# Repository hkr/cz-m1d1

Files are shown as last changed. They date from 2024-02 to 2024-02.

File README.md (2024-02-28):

# cz-m1d1
Alternative CZ-6BM1

Board cuts and footprints are from Midiori project.
Some footprints and symbols are downloaded from Digikey and/or Mouser.

## Testing status

### tested:
- MIDI out
- MIDI through/out2 switch
- MIDI through
- MIDI in only as part of MIDI through test

### untested:
- tape sync
- address and interrupt configurarion

## Changelog

- mk1 initial prototype
- mk2 change board design to match the look of the original CZ-6BM1
- minor silkscreen fix after that, but I have not built a card with it

## Pics
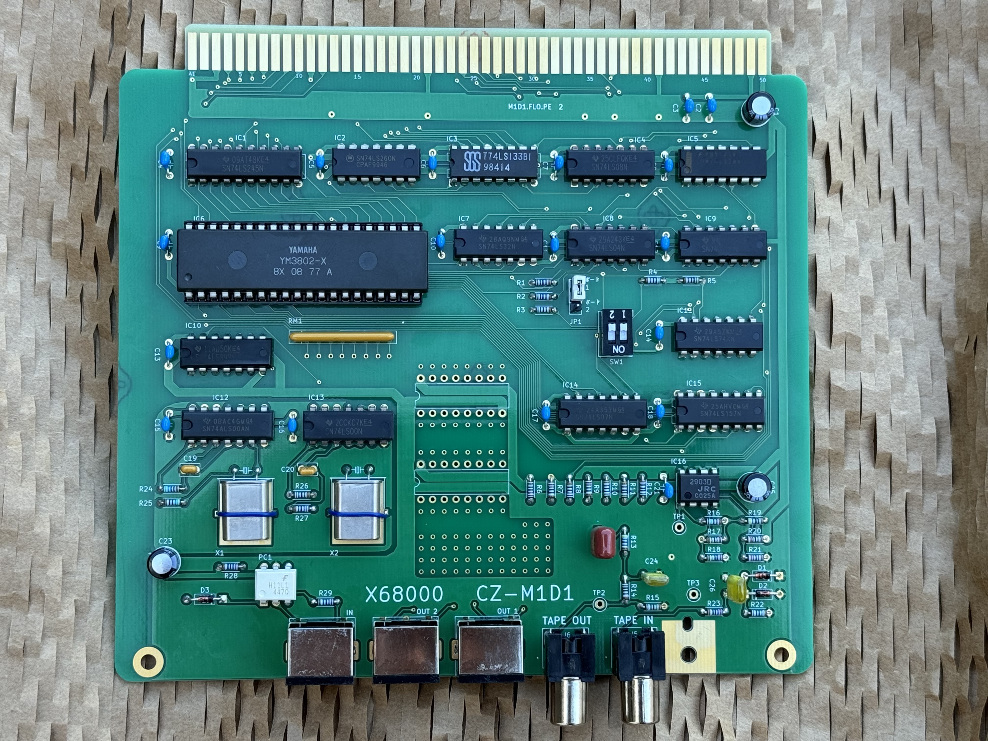
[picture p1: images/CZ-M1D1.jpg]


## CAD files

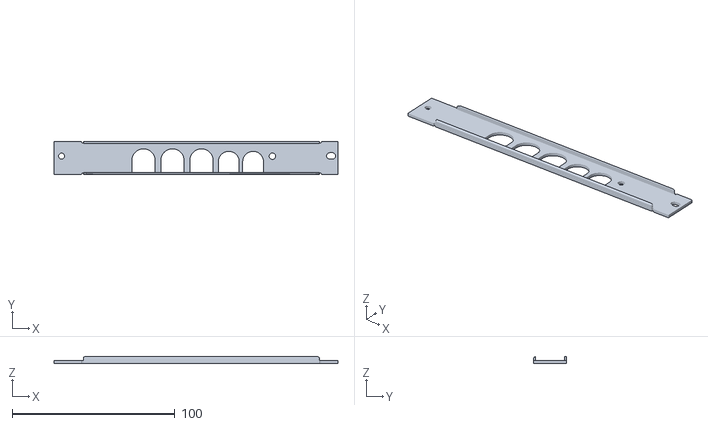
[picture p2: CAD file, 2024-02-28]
CZ-M1D1 cover.stl
174.6 x 20.3 x 4.00

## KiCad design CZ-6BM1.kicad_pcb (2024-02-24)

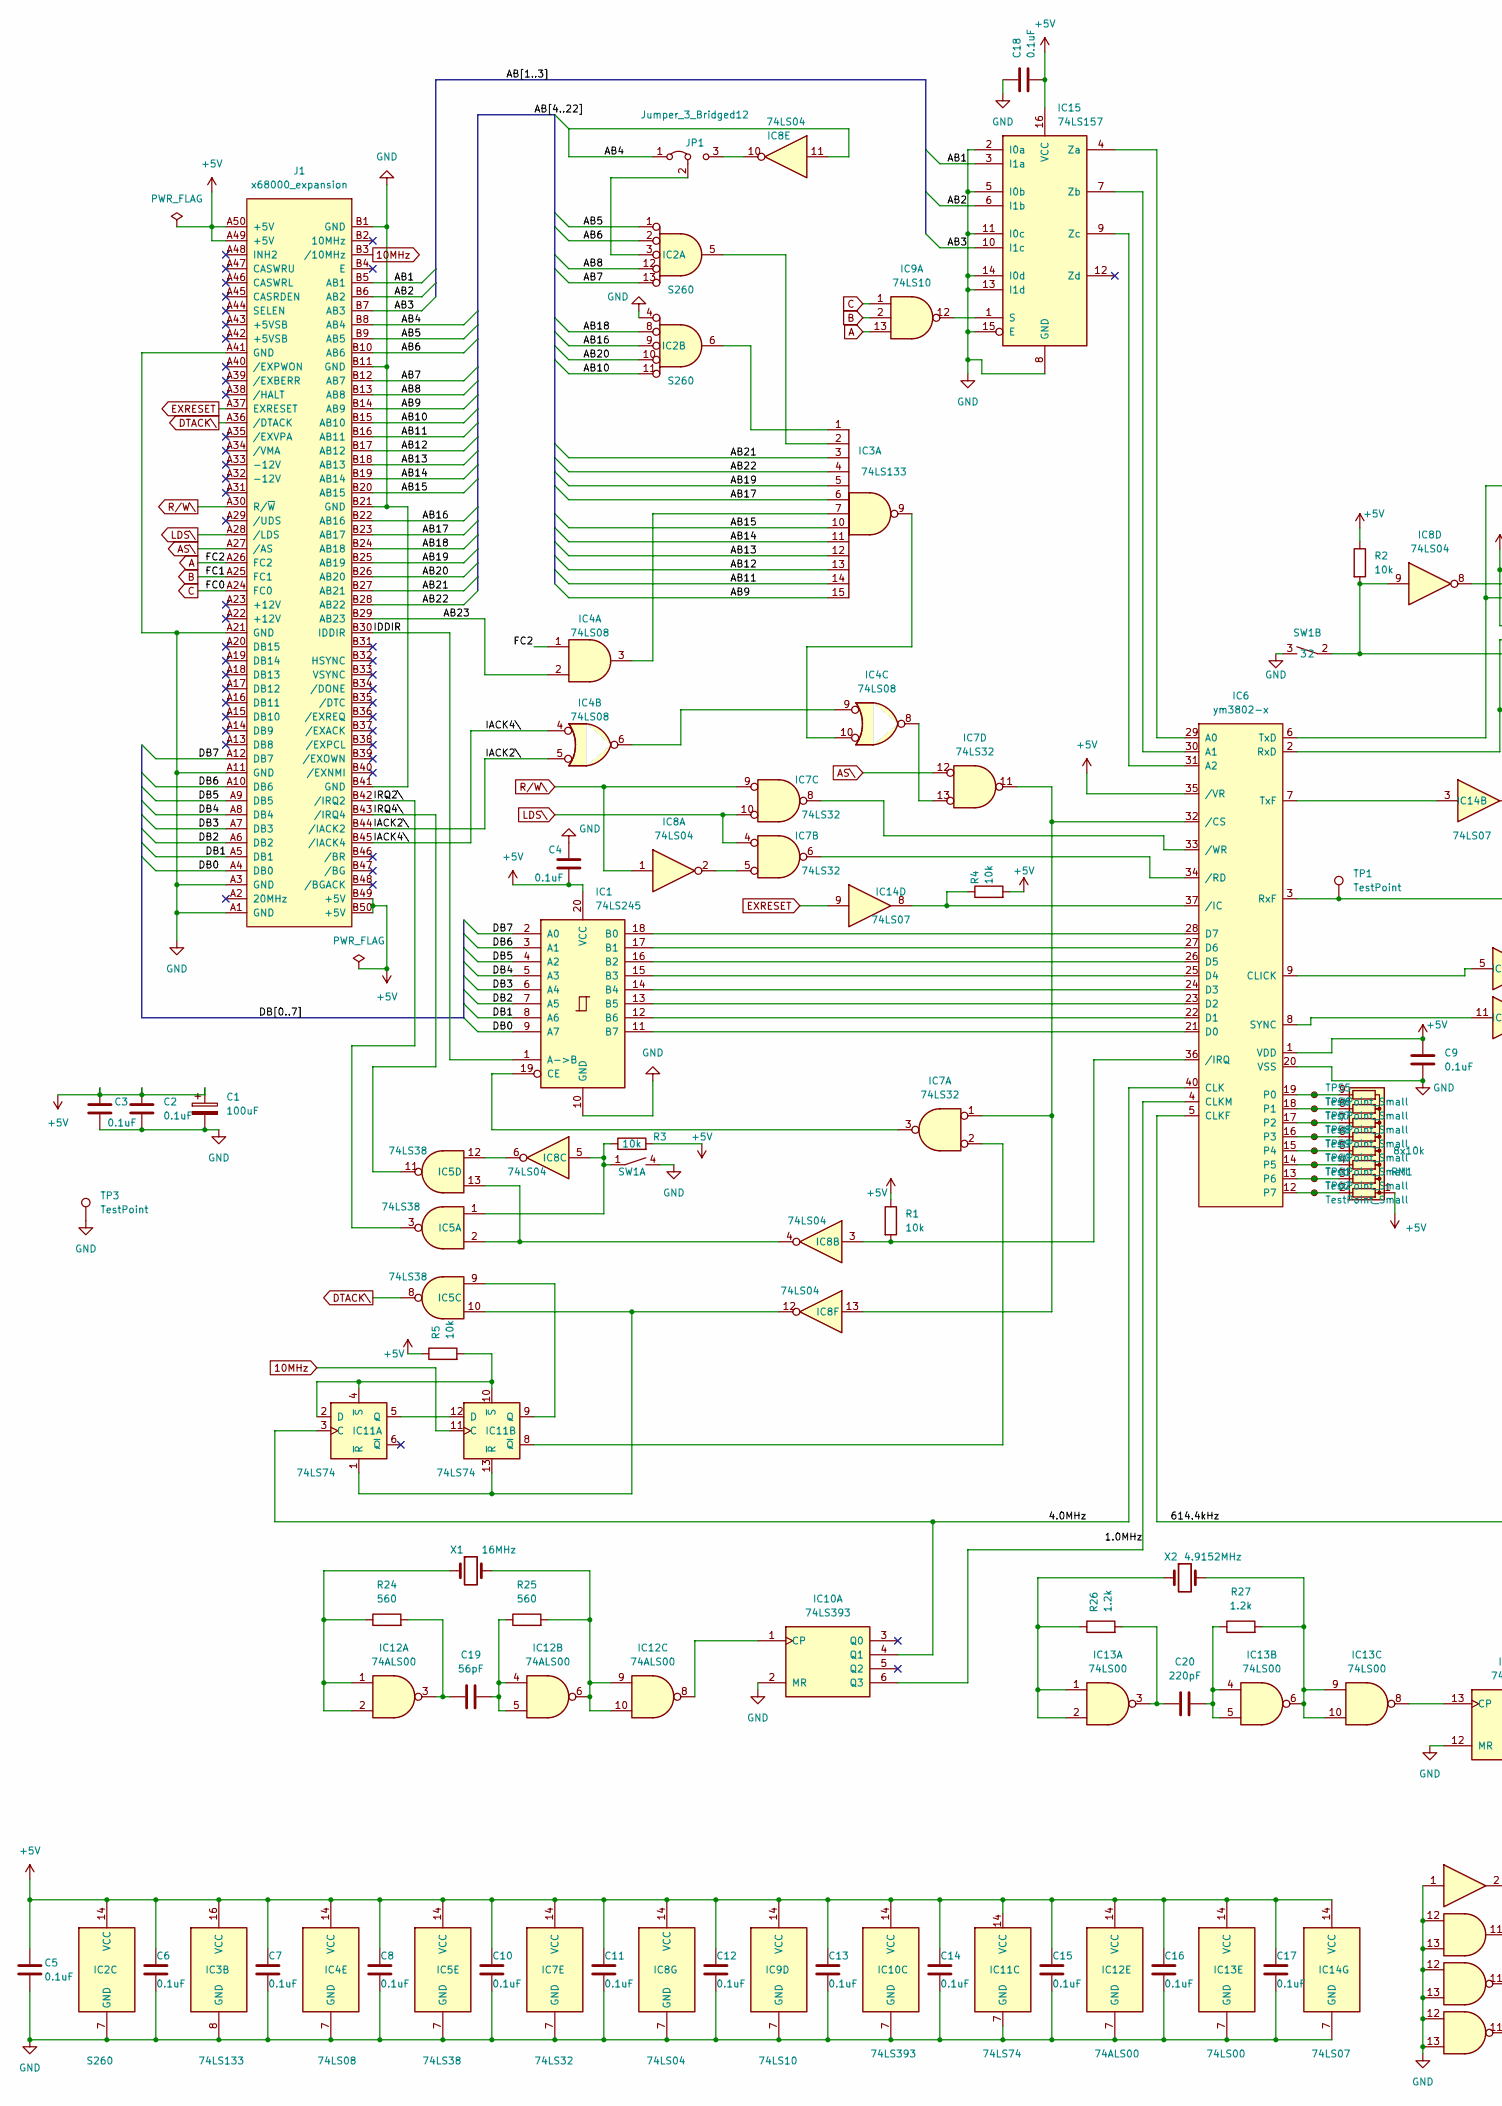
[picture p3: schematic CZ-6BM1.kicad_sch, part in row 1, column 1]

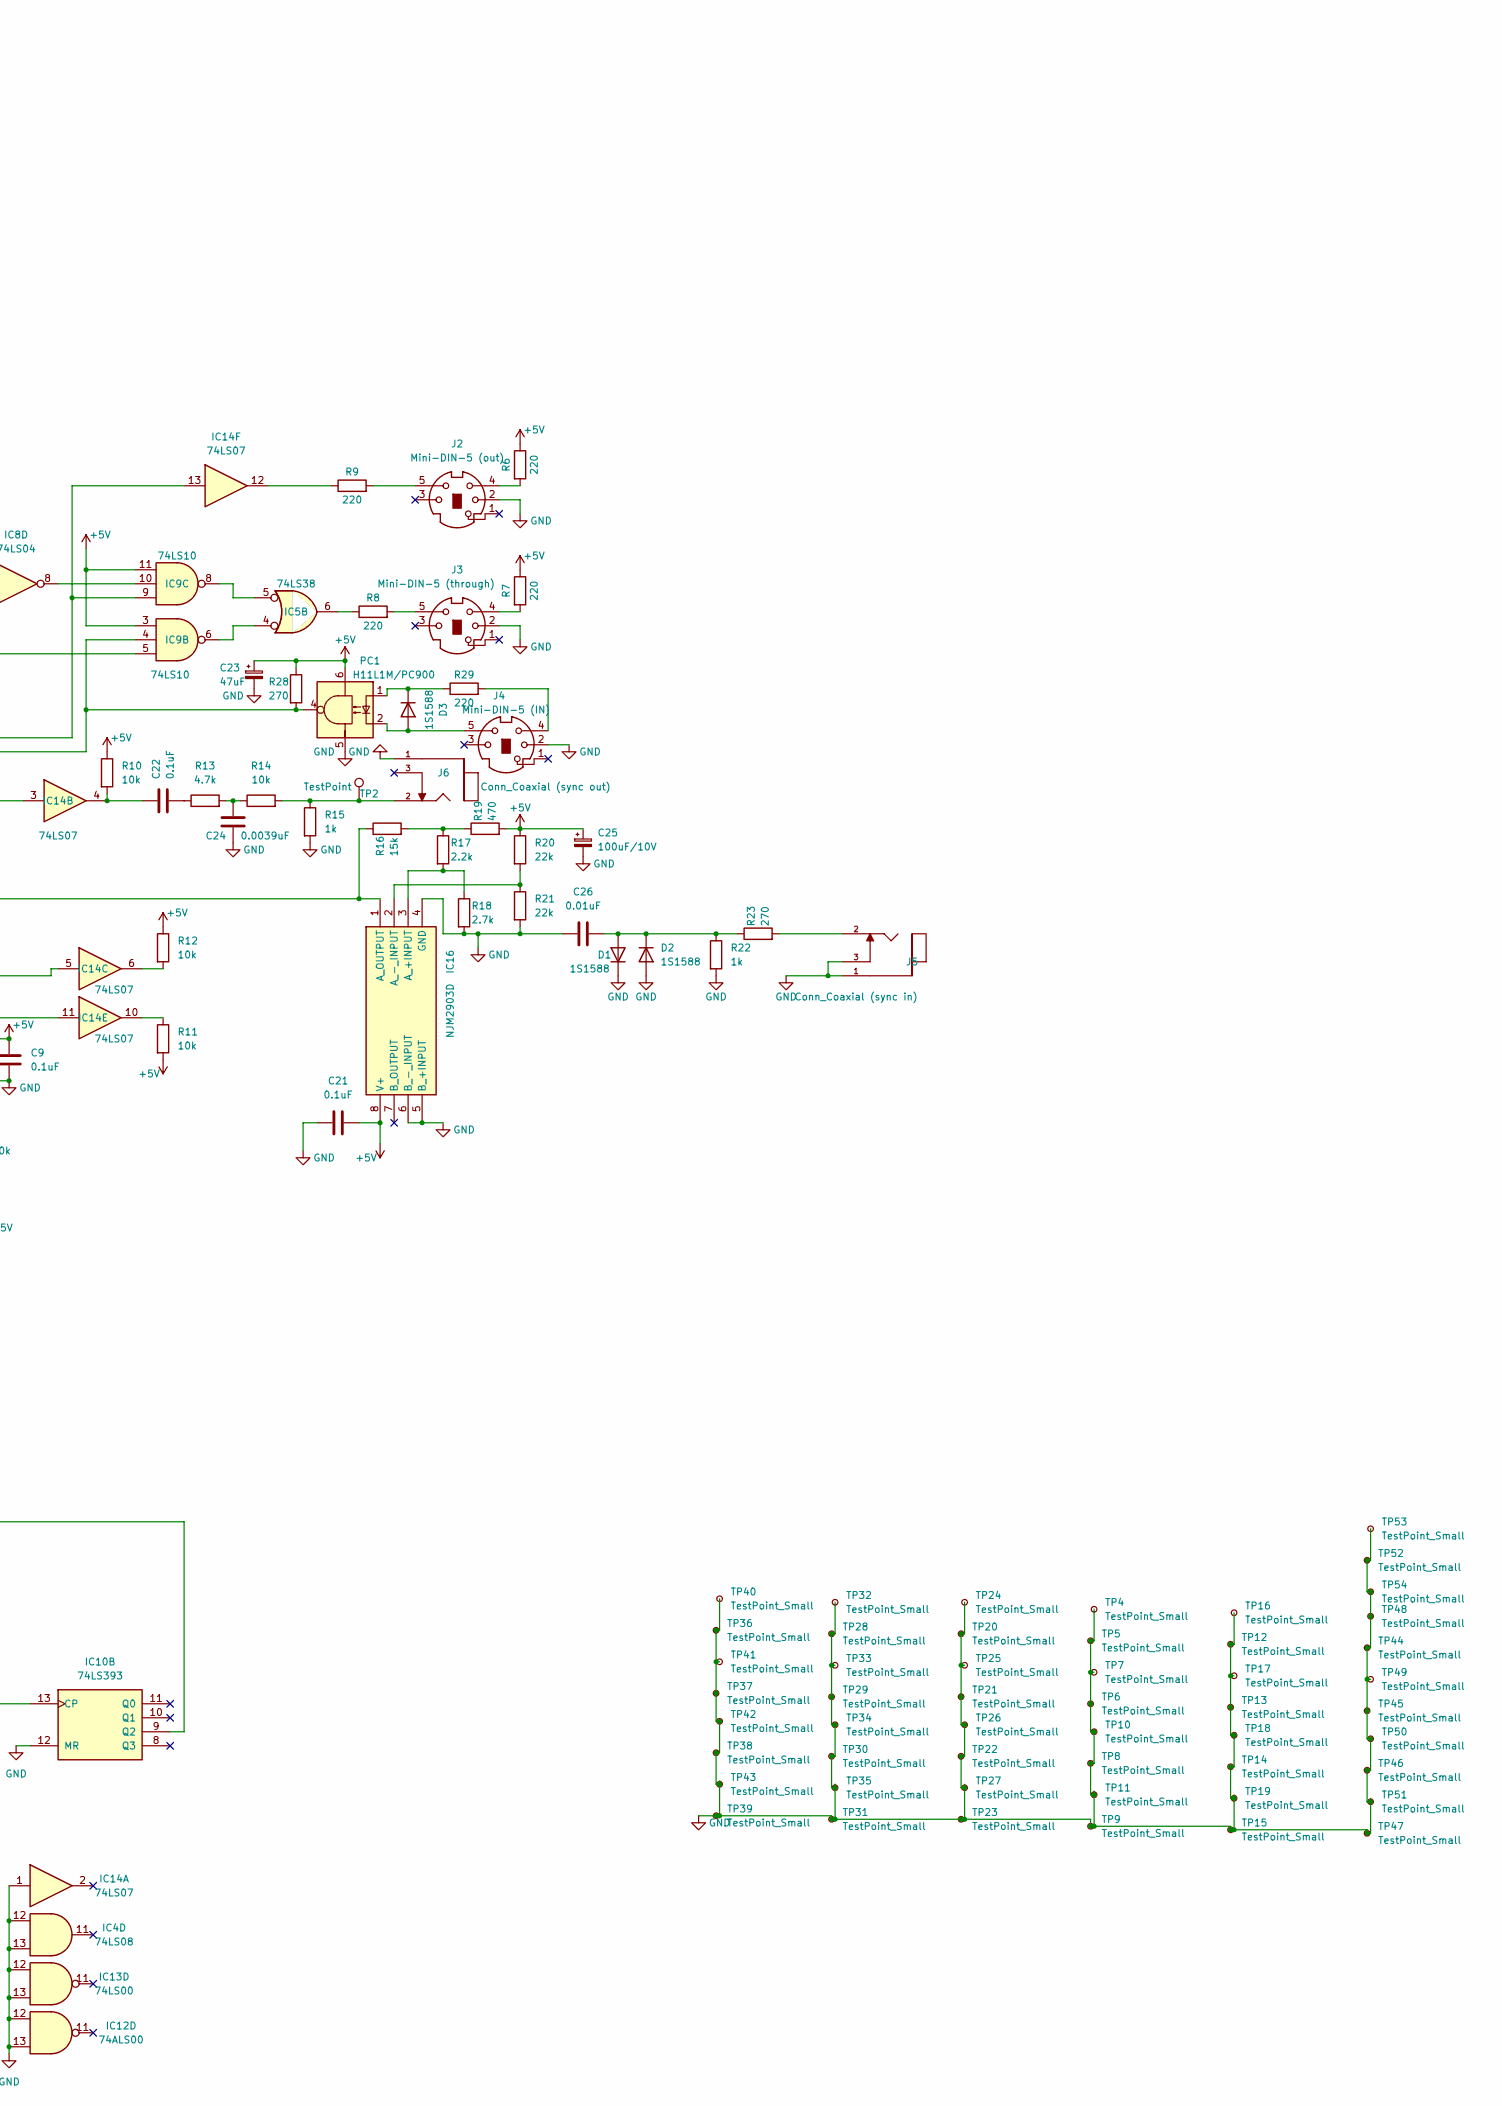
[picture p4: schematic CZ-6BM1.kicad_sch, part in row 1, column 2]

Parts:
C1: 100uF; CP_Radial_D6.3mm_P2.50mm
C2, C3, C4, C5, C6, C7, C8, C9, C10, C11, C12, C13, C14, C15, C16, C17, C18, C21: 0.1uF; C_Rect_L7.0mm_W2.5mm_P5.00mm
C19: 56pF; C_Rect_L4.0mm_W2.5mm_P2.50mm
C20: 220pF; C_Rect_L4.0mm_W2.5mm_P2.50mm
C22: 0.1uF; ECQE2104JB
C23: 47uF; CP_Radial_D6.3mm_P2.50mm
C24: 0.0039uF; CAP_QYX_3P5X6X8P5_NCH
C25: 100uF/10V; CP_Radial_D6.3mm_P2.50mm
C26: 0.01uF; CAP_QYX_3P5X6X8P5_NCH
D1, D2, D3: 1S1588; D_DO-35_SOD27_P7.62mm_Horizontal
IC1: 74LS245; DIP-20_W7.62mm
IC2: S260; DIP-14_W7.62mm
IC3: 74LS133; DIP-16_W7.62mm
IC4: 74LS08; DIP-14_W7.62mm
IC5: 74LS38; DIP-14_W7.62mm
IC6: ym3802-x; DIP-40_W15.24mm
IC7: 74LS32; DIP-14_W7.62mm
IC8: 74LS04; DIP-14_W7.62mm
IC9: 74LS10; DIP-14_W7.62mm
IC10: 74LS393; DIP-14_W7.62mm
IC11: 74LS74; DIP-14_W7.62mm
IC12: 74ALS00; DIP-14_W7.62mm
IC13: 74LS00; DIP-14_W7.62mm
IC14: 74LS07; DIP-14_W7.62mm
IC15: 74LS157; DIP-16_W7.62mm
IC16: NJM2903D; DIP762W56P254L880H425Q8N; Mouser Part Number 513-NJM2903D
J1: x68000_expansion
J2: Mini-DIN-5 (out); MD-50SM
J3: Mini-DIN-5 (through); MD-50SM
J4: Mini-DIN-5 (IN); MD-50SM
J5: Conn_Coaxial (sync in); SWITCHCRAFT_PJRAN1X1U01X; PART_REV B
J6: Conn_Coaxial (sync out); SWITCHCRAFT_PJRAN1X1U01X; PART_REV B
JP1: Jumper_3_Bridged12; PinHeader_1x03_P2.54mm_Vertical
PC1: H11L1M/PC900; DIP-6_W7.62mm
R1, R2, R3, R4, R5, R10, R11, R12, R14: 10k; R_Axial_DIN0204_L3.6mm_D1.6mm_P5.08mm_Horizontal
R6, R7, R8, R9, R29: 220; R_Axial_DIN0204_L3.6mm_D1.6mm_P5.08mm_Horizontal
R13: 4.7k; R_Axial_DIN0204_L3.6mm_D1.6mm_P5.08mm_Horizontal
R15, R22: 1k; R_Axial_DIN0204_L3.6mm_D1.6mm_P5.08mm_Horizontal
R16: 15k; R_Axial_DIN0204_L3.6mm_D1.6mm_P5.08mm_Horizontal
R17: 2.2k; R_Axial_DIN0204_L3.6mm_D1.6mm_P5.08mm_Horizontal
R18: 2.7k; R_Axial_DIN0204_L3.6mm_D1.6mm_P5.08mm_Horizontal
R19: 470; R_Axial_DIN0204_L3.6mm_D1.6mm_P5.08mm_Horizontal
R20, R21: 22k; R_Axial_DIN0204_L3.6mm_D1.6mm_P5.08mm_Horizontal
R23, R28: 270; R_Axial_DIN0204_L3.6mm_D1.6mm_P5.08mm_Horizontal
R24, R25: 560; R_Axial_DIN0204_L3.6mm_D1.6mm_P5.08mm_Horizontal
R26, R27: 1.2k; R_Axial_DIN0204_L3.6mm_D1.6mm_P5.08mm_Horizontal
RM1: 8x10k; R_Array_SIP9
SW1: SW_DIP_SPSTx02_Slide_9.78x7.26mm_W7.62mm_P2.54mm
TP1, TP2, TP3: TestPoint; TestPoint_Loop_D2.50mm_Drill1.0mm
TP4, TP5, TP6, TP7, TP8, TP9, TP10, TP11, TP12, TP13, TP14, TP15, TP16, TP17, TP18, TP19, TP20, TP21, TP22, TP23, TP24, TP25, TP26, TP27, TP28, TP29, TP30, TP31, TP32, TP33, TP34, TP35, TP36, TP37, TP38, TP39, TP40, TP41, TP42, TP43, TP44, TP45, TP46, TP47, TP48, TP49, TP50, TP51, TP52, TP53, TP54, TP55, TP56, TP57, TP58, TP59, TP60, TP61, TP62: TestPoint_Small; TestPoint_THTPad_D1.0mm_Drill0.5mm
X1: 16MHz; Crystal_HC49-U_Horizontal_1EP_style2
X2: 4.9152MHz; Crystal_HC49-U_Horizontal_1EP_style2

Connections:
10MHz: IC11.11 (C), J1.B3 (/10MHz)
+5V: C1.1, C2.1, C3.1, C4.2, C5.1, C6.1, C7.1, C8.1, C9.1, C10.1, C11.1, C12.1, C13.1, C14.1, C15.1, C16.1, C17.1, C18.2, C21.2, C23.1, C25.1, IC1.20 (VCC), IC2.14 (VCC), IC3.16 (VCC), IC4.14 (VCC), IC5.14 (VCC), IC6.1 (VDD), IC6.35 (/VR), IC7.14 (VCC), IC8.14 (VCC), IC9.3, IC9.11, IC9.14 (VCC), IC10.14 (VCC), IC11.14 (VCC), IC12.14 (VCC), IC13.14 (VCC), IC14.14 (VCC), IC15.16 (VCC), IC16.8 (V+), J1.A49 (+5V), J1.A50 (+5V), J1.B49 (+5V), J1.B50 (+5V), PC1.6, R1.1, R2.1, R3.2, R4.2, R5.1, R6.1, R7.1, R10.1, R11.2, R12.1, R19.2, R20.1, R28.1, RM1.1 (common)
/1.0MHz: IC6.4 (CLKM), IC10.6 (Q3)
/4.0MHz: IC6.40 (CLK), IC10.4 (Q1), IC11.3 (C)
/614.4kHz: IC6.5 (CLKF), IC10.9 (Q2)
/AB1: IC15.3 (I1a), J1.B5 (AB1)
/AB2: IC15.6 (I1b), J1.B6 (AB2)
/AB3: IC15.10 (I1c), J1.B7 (AB3)
/AB4: IC8.11, J1.B8 (AB4), JP1.1 (A)
/AB5: IC2.1, J1.B9 (AB5)
/AB6: IC2.2, J1.B10 (AB6)
/AB7: IC2.13, J1.B12 (AB7)
/AB8: IC2.12, J1.B13 (AB8)
/AB9: IC3.15, J1.B14 (AB9)
/AB10: IC2.11, J1.B15 (AB10)
/AB11: IC3.14, J1.B16 (AB11)
/AB12: IC3.13, J1.B17 (AB12)
/AB13: IC3.12, J1.B18 (AB13)
/AB14: IC3.11, J1.B19 (AB14)
/AB15: IC3.10, J1.B20 (AB15)
/AB16: IC2.9, J1.B22 (AB16)
/AB17: IC3.6, J1.B23 (AB17)
/AB18: IC2.8, J1.B24 (AB18)
/AB19: IC3.5, J1.B25 (AB19)
/AB20: IC2.10, J1.B26 (AB20)
/AB21: IC3.3, J1.B27 (AB21)
/AB22: IC3.4, J1.B28 (AB22)
/AB23: IC4.2, J1.B29 (AB23)
/DB0: IC1.9 (A7), J1.A4 (DB0)
/DB1: IC1.8 (A6), J1.A5 (DB1)
/DB2: IC1.7 (A5), J1.A6 (DB2)
/DB3: IC1.6 (A4), J1.A7 (DB3)
/DB4: IC1.5 (A3), J1.A8 (DB4)
/DB5: IC1.4 (A2), J1.A9 (DB5)
/DB6: IC1.3 (A1), J1.A10 (DB6)
/DB7: IC1.2 (A0), J1.A12 (DB7)
/IACK2\: IC4.5, J1.B44 (/IACK2)
/IACK4\: IC4.4, J1.B45 (/IACK4)
/IDDIR: IC1.1 (A->B), J1.B30 (IDDIR)
/IRQ2\: IC5.3, J1.B42 (/IRQ2)
/IRQ4\: IC5.11, J1.B43 (/IRQ4)
A: IC4.1, IC9.13, J1.A26 (FC2)
AS\: IC7.12, J1.A27 (/AS)
B: IC9.2, J1.A25 (FC1)
C: IC9.1, J1.A24 (FC0)
DTACK\: IC5.8, J1.A36 (/DTACK)
EXRESET: IC14.9, J1.A37 (EXRESET)
GND: C1.2, C2.2, C3.2, C4.1, C5.2, C6.2, C7.2, C8.2, C9.2, C10.2, C11.2, C12.2, C13.2, C14.2, C15.2, C16.2, C17.2, C18.1, C21.1, C23.2, C24.2, C25.2, C26.1, D1.1 (K), D2.2 (A), IC1.10 (GND), IC2.4, IC2.7 (GND), IC3.8 (GND), IC4.7 (GND), IC4.12, IC4.13, IC5.7 (GND), IC6.20 (VSS), IC7.7 (GND), IC8.7 (GND), IC9.7 (GND), IC10.2 (MR), IC10.7 (GND), IC10.12 (MR), IC11.7 (GND), IC12.7 (GND), IC12.12, IC12.13, IC13.7 (GND), IC13.12, IC13.13, IC14.1, IC14.7 (GND), IC15.2 (I0a), IC15.5 (I0b), IC15.8 (GND), IC15.11 (I0c), IC15.13 (I1d), IC15.14 (I0d), IC15.15 (E), IC16.4 (GND), IC16.5 (B_+INPUT), IC16.6 (B_-_INPUT), J1.A1 (GND), J1.A3 (GND), J1.A11 (GND), J1.A21 (GND), J1.A41 (GND), J1.B1 (GND), J1.B11 (GND), J1.B21 (GND), J1.B41 (GND), J2.2, J3.2, J4.2, J5.1, J5.3, J6.1, PC1.5, R15.2, R18.2, R21.2, R22.2, SW1.3, SW1.4, TP3.1, TP4.1, TP5.1, TP6.1, TP7.1, TP8.1, TP9.1, TP10.1, TP11.1, TP12.1, TP13.1, TP14.1, TP15.1, TP16.1, TP17.1, TP18.1, TP19.1, TP20.1, TP21.1, TP22.1, TP23.1, TP24.1, TP25.1, TP26.1, TP27.1, TP28.1, TP29.1, TP30.1, TP31.1, TP32.1, TP33.1, TP34.1, TP35.1, TP36.1, TP37.1, TP38.1, TP39.1, TP40.1, TP41.1, TP42.1, TP43.1, TP44.1, TP45.1, TP46.1, TP47.1, TP48.1, TP49.1, TP50.1, TP51.1, TP52.1, TP53.1, TP54.1
LDS\: IC7.4, IC7.10, J1.A28 (/LDS)
unnamed: C19.1, IC12.3, R24.2
unnamed: C19.2, IC12.4, IC12.5, R25.1
unnamed: C20.1, IC13.3, R26.2
unnamed: C20.2, IC13.4, IC13.5, R27.1
unnamed: C22.1, IC14.4, R10.2
unnamed: C22.2, R13.1
unnamed: C24.1, R13.2, R14.1
unnamed: C26.2, D1.2 (A), D2.1 (K), R22.1, R23.1
unnamed: D3.2 (A), J4.5, PC1.2
unnamed: D3.1 (K), PC1.1, R29.1
unnamed: IC1.18 (B0), IC6.28 (D7)
unnamed: IC1.17 (B1), IC6.27 (D6)
unnamed: IC1.16 (B2), IC6.26 (D5)
unnamed: IC1.15 (B3), IC6.25 (D4)
unnamed: IC1.14 (B4), IC6.24 (D3)
unnamed: IC1.13 (B5), IC6.23 (D2)
unnamed: IC1.12 (B6), IC6.22 (D1)
unnamed: IC1.11 (B7), IC6.21 (D0)
unnamed: IC1.19 (CE), IC7.3
unnamed: IC2.5, IC3.2
unnamed: IC2.6, IC3.1
unnamed: IC3.7, IC4.3
unnamed: IC3.9, IC4.10
unnamed: IC4.6, IC4.9
unnamed: IC4.8, IC7.13
unnamed: IC5.1, IC8.5, R3.1, SW1.1
unnamed: IC5.4, IC9.6
unnamed: IC5.5, IC9.8
unnamed: IC5.6, R8.1
unnamed: IC5.12, IC8.6
unnamed: IC5.2, IC5.13, IC8.4
unnamed: IC6.9 (CLICK), IC14.5
unnamed: IC6.19 (P0), RM1.9 (R8), TP55.1
unnamed: IC6.18 (P1), RM1.8 (R7), TP56.1
unnamed: IC6.17 (P2), RM1.7 (R6), TP57.1
unnamed: IC6.16 (P3), RM1.6 (R5), TP58.1
unnamed: IC6.15 (P4), RM1.5 (R4), TP59.1
unnamed: IC6.14 (P5), RM1.4 (R3), TP60.1
unnamed: IC6.13 (P6), RM1.3 (R2), TP61.1
unnamed: IC6.12 (P7), RM1.2 (R1), TP62.1
unnamed: IC6.2 (RxD), IC9.4, PC1.4, R28.2
unnamed: IC6.8 (SYNC), IC14.11
unnamed: IC6.6 (TxD), IC9.9, IC14.13
unnamed: IC6.7 (TxF), IC14.3
unnamed: IC6.32 (/CS), IC7.1, IC7.11, IC8.13
unnamed: IC6.37 (/IC), IC14.8, R4.1
unnamed: IC6.36 (/IRQ), IC8.3, R1.2
unnamed: IC6.34 (/RD), IC7.6
unnamed: IC6.33 (/WR), IC7.8
unnamed: IC7.5, IC8.2
unnamed: IC8.8, IC9.10
unnamed: IC8.9, IC9.5, R2.2, SW1.2
unnamed: IC10.1 (CP), IC12.8
unnamed: IC10.13 (CP), IC13.8
unnamed: IC11.2 (D), IC11.4 (~S), IC11.10 (~S), R5.2
unnamed: IC11.5 (Q), IC11.12 (D)
unnamed: IC5.10, IC8.12, IC11.1 (~R), IC11.13 (~R)
unnamed: IC5.9, IC11.9 (Q)
unnamed: IC7.2, IC11.8 (~Q)
unnamed: IC12.1, IC12.2, R24.1, X1.1
unnamed: IC12.6, IC12.9, IC12.10, R25.2, X1.2
unnamed: IC13.1, IC13.2, R26.1, X2.1
unnamed: IC13.6, IC13.9, IC13.10, R27.2, X2.2
unnamed: IC14.6, R12.2
unnamed: IC14.10, R11.1
unnamed: IC14.12, R9.1
unnamed: IC9.12, IC15.1 (S)
unnamed: IC6.29 (A0), IC15.4 (Za)
unnamed: IC6.30 (A1), IC15.7 (Zb)
unnamed: IC6.31 (A2), IC15.9 (Zc)
unnamed: IC16.3 (A_+INPUT), R17.2, R18.1
unnamed: IC16.2 (A_-_INPUT), R20.2, R21.1
unnamed: IC6.3 (RxF), IC16.1 (A_OUTPUT), R16.1, TP1.1
unnamed: J2.4, R6.2
unnamed: J2.5, R9.2
unnamed: J3.4, R7.2
unnamed: J3.5, R8.2
unnamed: J4.4, R29.2
unnamed: J5.2, R23.2
unnamed: J6.2, R14.2, R15.1, TP2.1
unnamed: IC8.10, JP1.3 (B)
unnamed: IC2.3, JP1.2 (C)
unnamed: R16.2, R17.1, R19.1
R/W\: IC7.9, IC8.1, J1.A30 (R/~W)

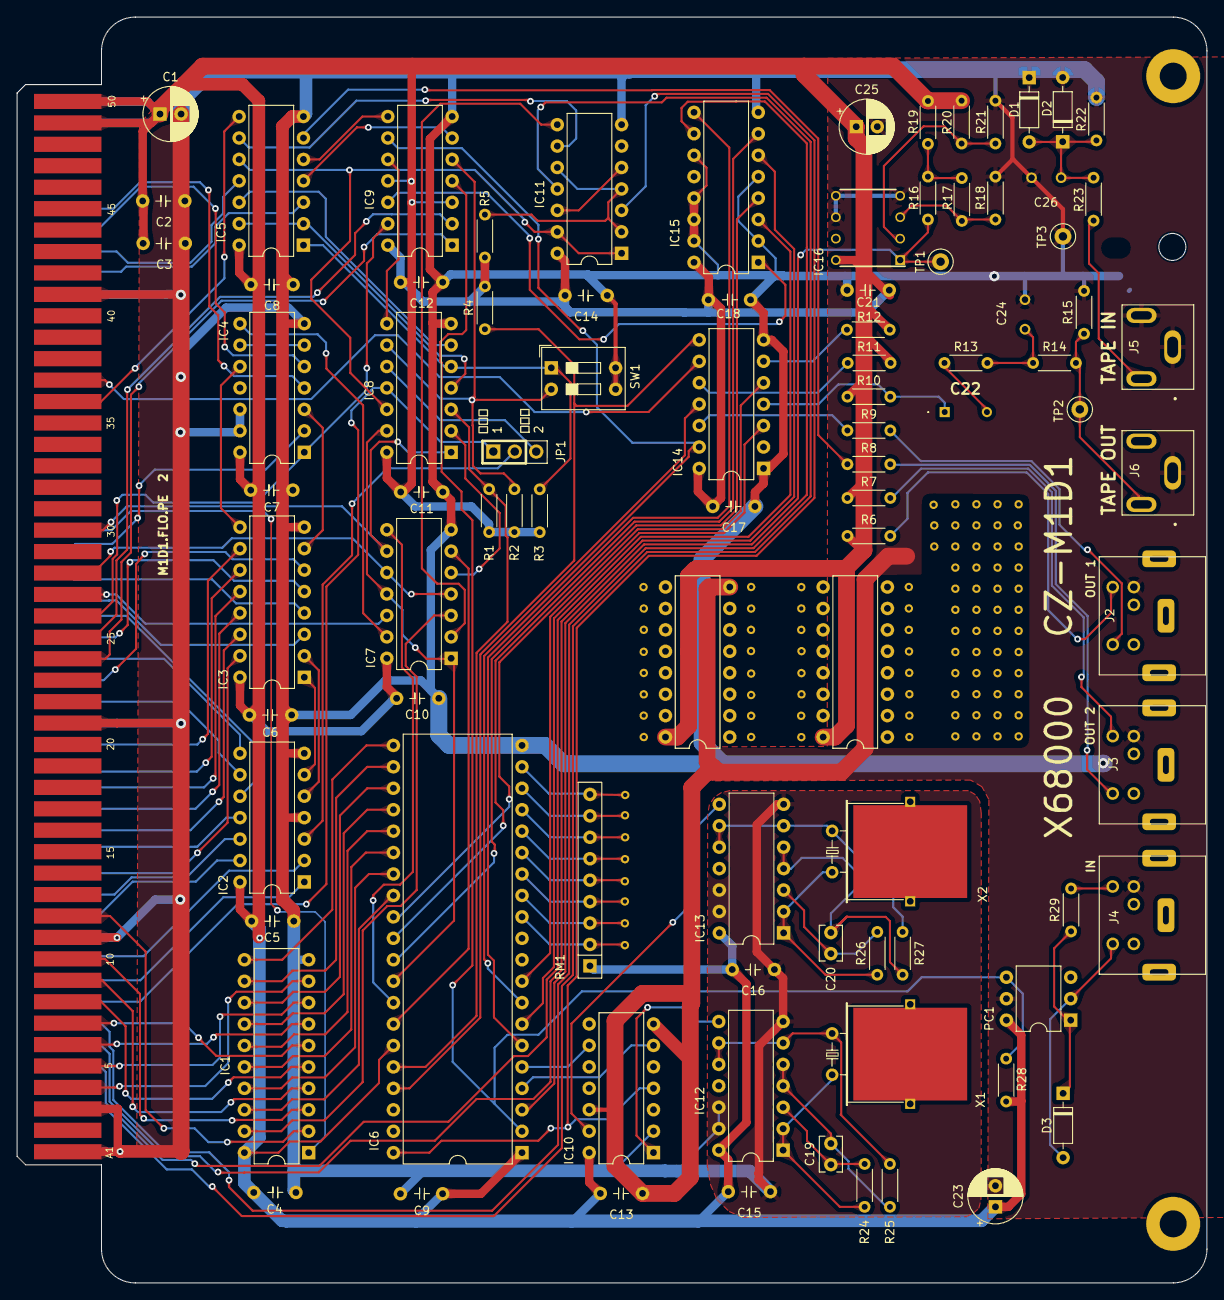
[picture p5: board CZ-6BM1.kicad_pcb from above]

Board: 2 copper layers, 141.0 x 150.0 mm, 179 parts (0 on the bottom side), 133 nets.

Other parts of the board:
H1, H2: MountingHole; MountingHole_3.2mm_M3_Pad
TP45#2, TP45#3, TP45#4, TP45#5, TP45#6, TP45#7, TP45#8, TP45#9, TP45#10, TP45#11, TP45#12, TP45#13, TP45#14, TP45#15, TP45#16, TP45#17, TP45#18, TP45#19, TP45#20, TP45#21, TP45#22, TP45#23, TP45#24, TP45#25, TP45#26, TP45#27, TP45#28, TP45#29, TP45#30: TestPoint_Small; TestPoint_THTPad_D1.0mm_Drill0.5mm

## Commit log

2024-02-24 Silkscreen fix
    [CZ-6BM1-B_Cu.gbr, CZ-6BM1-B_Mask.gbr, CZ-6BM1-B_Paste.gbr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]
2024-02-28 Added cover plate Based on https://www.thingiverse.com/thing:2582761
    [CZ-M1D1 cover.stl]
